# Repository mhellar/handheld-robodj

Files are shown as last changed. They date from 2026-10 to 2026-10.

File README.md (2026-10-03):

# Handheld Robo DJ

A pocket robot-voice DJ on an ESP32-S3. **SAM** (the 1982 Software Automatic Mouth speech synth) pre-renders a bank of
words into memory, and a "turntable deck" plays, scratches, stutters and reverses them over a drum machine, with a
16-step sequencer, granular and vocoder voice effects and a sci-fi HUD on a 128x128 OLED. Four buttons, one speaker.

The board is a single-sided PCB designed to be **milled on a desktop CNC** (all copper on the bottom, big pads, no
jumper wires). The modules plug into female headers, so there's no SMD soldering.

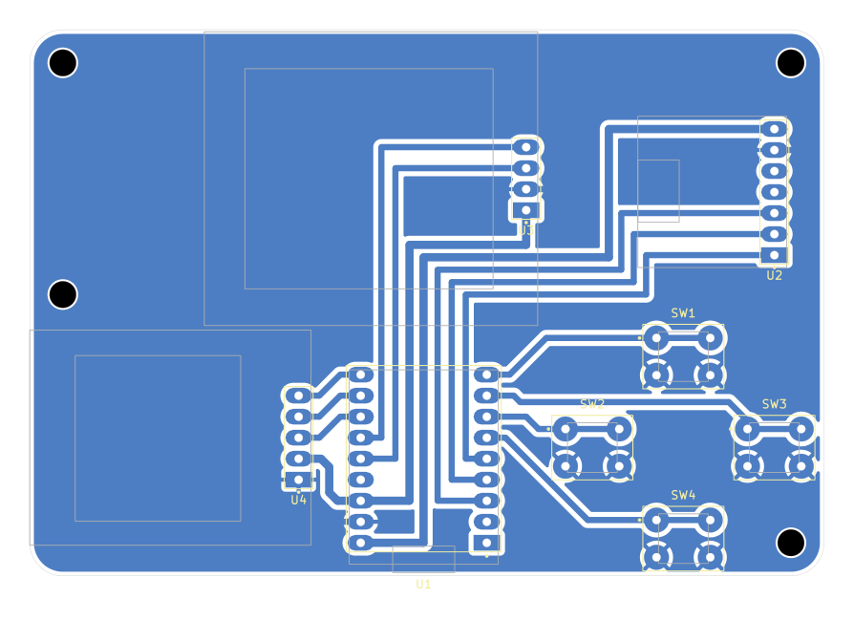
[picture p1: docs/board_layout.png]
board layout


## What's in here

| Folder | Contents |
|---|---|
| `firmware/handheld_robodj/` | The Robo DJ sketch (Arduino), SAM's C core bundled alongside |
| `firmware/handheld_bringup/` | Bring-up / test sketch: I2C scan, buttons, joystick, OLED, beep. Flash this first |
| `hardware/kicad/` | KiCad project (schematic, PCB, custom symbols + footprints in `s3_cnc.pretty`) |
| `hardware/cnc/` | Gerbers + Excellon drills, ready-made G-code for a Genmitsu Cubiko (GRBL), the FlatCAM script, a 1:1 print for checking parts fit, and `CNC_CHEATSHEET.txt` |
| `docs/` | Board layout image |

## Parts

| Ref | Part | Notes |
|---|---|---|
| U1 | ESP32-S3 **SuperMini** | 2x 1x9 female headers. One with PSRAM (e.g. 4 MB flash / 2 MB PSRAM) holds the most words |
| U2 | MAX98357A I2S amp breakout | 1x7 female header, VIN on 5 V, plus a small 4-8 ohm speaker |
| U3 | 1.5" 128x128 OLED, **SH1107**, I2C | 1x4 female header (VCC GND SCL SDA), e.g. GME128128-01-IIC |
| U4 | KY-023 joystick module | 1x5 female header. Swap its right-angle pins for straight ones. Not used by Robo DJ, the bring-up sketch tests it |
| SW1-SW4 | 6 mm tact buttons | the diamond: UP / LEFT / RIGHT / DOWN |
| | 100 x 70 mm single-sided copper clad | board is 96 x 66 mm, M3 holes |

## Pinout

| Function | GPIO |
|---|---|
| OLED SDA / SCL | 11 / 12 |
| Amp DIN / BCLK / LRC | 1 / 2 / 3 |
| Buttons UP / RIGHT / LEFT / DOWN | 7 / 6 / 5 / 4 (to GND, internal pull-ups) |
| Joystick X / Y / SW | 10 / 9 / 8 (on 3V3) |

## Build the firmware

1. Arduino IDE (or arduino-cli) with the **ESP32 core 3.x** and the **U8g2** library.
2. Board settings: **ESP32S3 Dev Module**, **USB CDC On Boot: Enabled**, **PSRAM: QSPI PSRAM** (it runs without PSRAM, with fewer words).
   arduino-cli FQBN: `esp32:esp32:esp32s3:CDCOnBoot=cdc,PSRAM=enabled`
3. Open `firmware/handheld_robodj/handheld_robodj.ino` and upload. Flash `handheld_bringup` first if you're bringing up a fresh board.

```
arduino-cli compile --fqbn esp32:esp32:esp32s3:CDCOnBoot=cdc,PSRAM=enabled firmware/handheld_robodj
arduino-cli upload  --fqbn esp32:esp32:esp32s3:CDCOnBoot=cdc,PSRAM=enabled -p COMx firmware/handheld_robodj
```

Tips:
- The OLED uses the `U8G2_SH1107_PIMORONI_128X128` constructor. The generic SH1107 one shifts the picture by 32 px.
- If the SuperMini sits silent after an upload, press its RST button. The auto-reset can leave it in the bootloader.
- Intermittent buttons on a milled board usually turn out to be a solder bridge between neighbouring 2.54 mm pads.
- `handheld_bringup` prints to Serial every 250 ms: run it with a serial monitor open.

## Controls

Diamond: **UP = SHIFT**, **LEFT = VOICE**, **RIGHT = BEAT**, **DOWN = FX**. Live hits play instantly. With REC on they're quantized into the 16 steps.

| Button | tap | double | triple | hold |
|---|---|---|---|---|
| VOICE | say the word | next word | random word | SCRATCH it (tempo-synced) |
| BEAT | kick | snare | clap | hi-hat roll |
| FX | next FX | GROOVE on/off | | STUTTER |
| SHIFT + VOICE | REC on/off | clear voice track | clear all | REVERSE |
| SHIFT + BEAT | next scratch style | tempo | chord progression | TAPE STOP |
| SHIFT + FX | volume | next robot voice (re-renders the words) | | |
| SHIFT alone | MUTATE (new words, same rhythm) | AUTO (random beat + words) | | UNDERWATER |

- **Voice FX:** CLEAN, CRUSH, ECHO, GRAIN (slow cloud of grains at mixed pitches), SWARM (dense detuned robot choir), VOX (16-band vocoder on a chord, words stay clear), CHOIR (pure vocoder).
- **Scratch styles:** BABY, CHIRP, TRANSFORM, TEAR, FLARE.
- **Robot voices:** ROBOT, SAM, ELF, E.T., STUFFY, OLD LADY.
- **Words:** HELLO, ROBOT, YEAH, ERROR, DANCE, BEEP, BOOP, SYSTEM, ONLINE, WOW, FRESH, SCRATCH, ONE-FOUR, OH NO, COMPUTER, PARTY, FUNKY, AWESOME, DOES NOT COMPUTE. Edit `bank[]` in the sketch to make it say anything.

## Make the board

The PCB is single-sided with all copper on **B.Cu**, made for isolation milling. The Gerbers in `hardware/cnc/` also work at
a board house as a 1-layer board.

Milling order (details in `hardware/cnc/CNC_CHEATSHEET.txt`): 0.1 mm 20° V-bit isolation, 1.0 mm drill, 2.0 mm drill,
then V-bit outline score. The `.nc` files are ready to run on a GRBL machine. The drill files are already patched by
`fix_drill_spinup.py`, which fixes the spindle start for GRBL laser mode. To regenerate with FlatCAM, set the
path at the top of `load_and_mirror.tcl` and run it (File > Scripting > Run Script). It mirrors the board, because the
copper is on the bottom.

Before milling, print `PRINT_1to1_fit_test.pdf` at 100% and check your modules against it. The OLED and joystick
outlines were measured from photos.

## Credits and license

- **SAM** (Software Automatic Mouth) by Mark Barton / Don't Ask Software (1982). C port by Sebastian Macke,
  ESP8266SAM by Earle F. Philhower III. The C core is bundled in `firmware/handheld_robodj/`.
- **U8g2** by olikraus; **esp-dsp** and the ESP32 Arduino core by Espressif.
- Co-created by **Mark Hellar** and **Claude** (Anthropic). PCB milled and soldered by Mark Hellar.

Licensed under the **GNU GPL v3** (see `LICENSE`), the same as the bundled SAM core.

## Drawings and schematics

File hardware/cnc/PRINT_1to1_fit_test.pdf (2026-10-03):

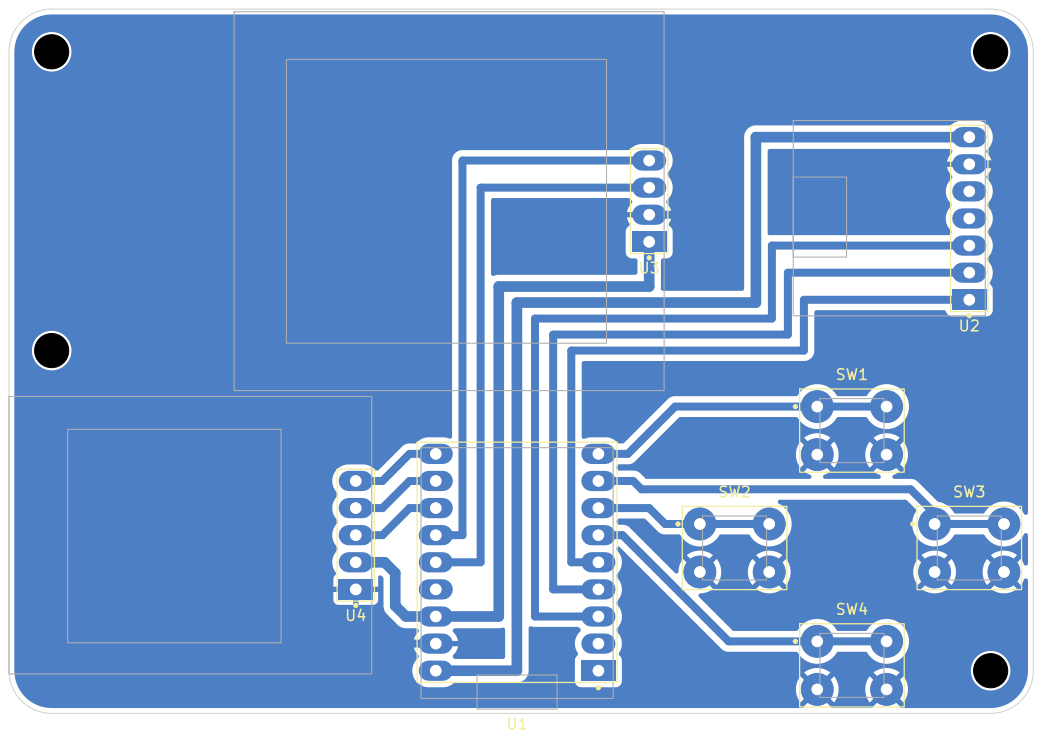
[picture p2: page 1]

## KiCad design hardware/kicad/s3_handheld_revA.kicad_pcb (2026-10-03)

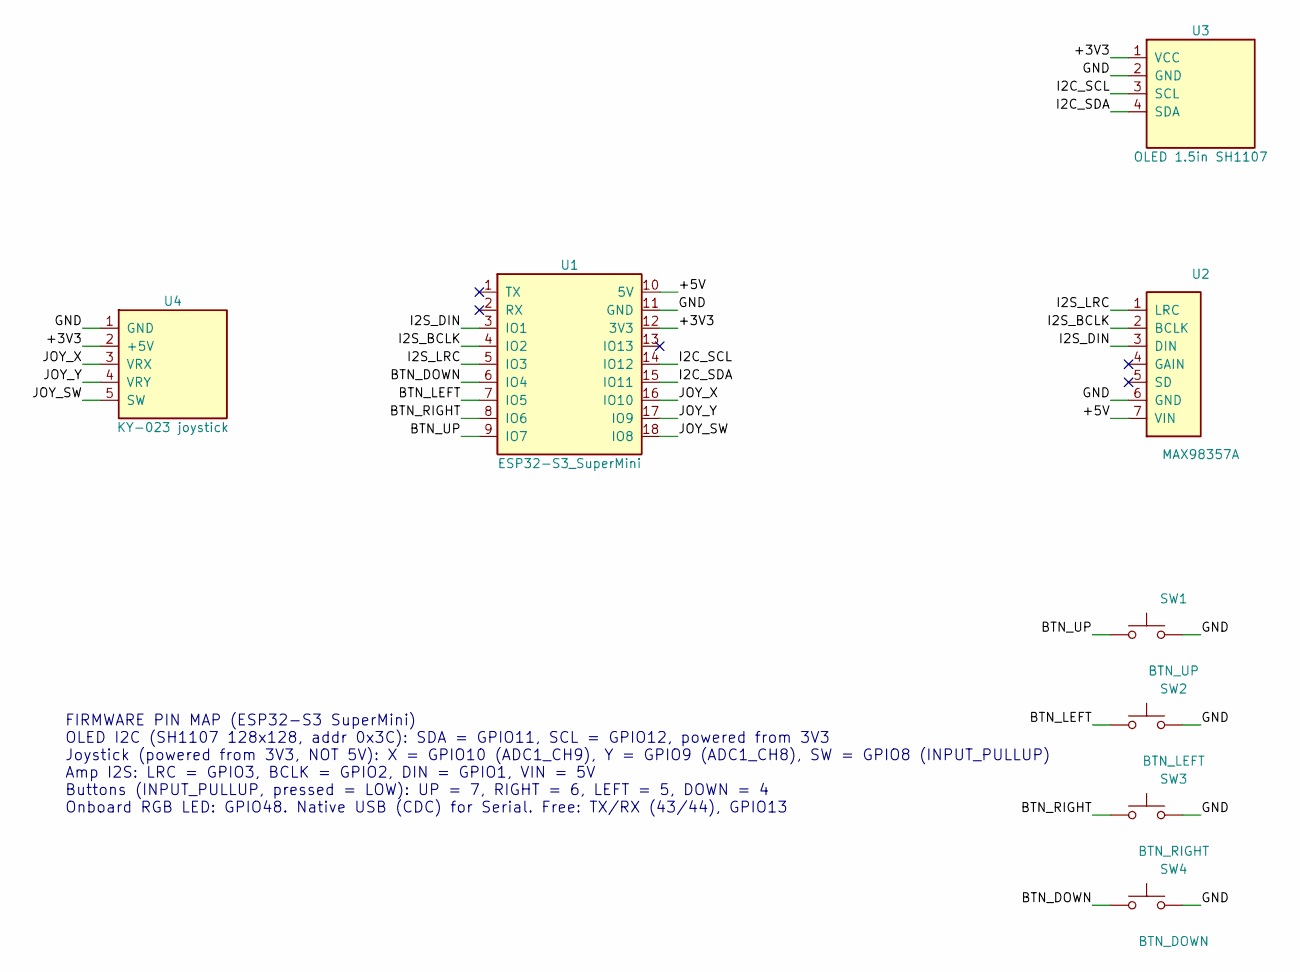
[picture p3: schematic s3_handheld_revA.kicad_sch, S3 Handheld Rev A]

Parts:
SW1: BTN_UP; SW_Tact_6mm_CNC
SW2: BTN_LEFT; SW_Tact_6mm_CNC
SW3: BTN_RIGHT; SW_Tact_6mm_CNC
SW4: BTN_DOWN; SW_Tact_6mm_CNC
U1: ESP32-S3_SuperMini; ESP32-S3_SuperMini_CNC
U2: MAX98357A; MAX98357A_Module_CNC
U3: OLED 1.5in SH1107; OLED_1.5in_128x128_I2C_CNC
U4: KY-023 joystick; Joystick_KY023_CNC

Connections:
/+3V3: U1.12 (3V3), U3.1 (VCC), U4.2 (+5V)
/+5V: U1.10 (5V), U2.7 (VIN)
/BTN_DOWN: SW4.1, U1.6 (IO4)
/BTN_LEFT: SW2.1, U1.7 (IO5)
/BTN_RIGHT: SW3.1, U1.8 (IO6)
/BTN_UP: SW1.1, U1.9 (IO7)
/GND: SW1.2, SW2.2, SW3.2, SW4.2, U1.11 (GND), U2.6 (GND), U3.2 (GND), U4.1 (GND)
/I2C_SCL: U1.14 (IO12), U3.3 (SCL)
/I2C_SDA: U1.15 (IO11), U3.4 (SDA)
/I2S_BCLK: U1.4 (IO2), U2.2 (BCLK)
/I2S_DIN: U1.3 (IO1), U2.3 (DIN)
/I2S_LRC: U1.5 (IO3), U2.1 (LRC)
/JOY_SW: U1.18 (IO8), U4.5 (SW)
/JOY_X: U1.16 (IO10), U4.3 (VRX)
/JOY_Y: U1.17 (IO9), U4.4 (VRY)

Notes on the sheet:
FIRMWARE PIN MAP (ESP32-S3 SuperMini) OLED I2C (SH1107 128x128, addr 0x3C): SDA = GPIO11, SCL = GPIO12, powered from 3V3 Joystick (powered from 3V3, NOT 5V): X = GPIO10 (ADC1_CH9), Y = GPIO9 (ADC1_CH8), SW = GPIO8 (INPUT_PULLUP) Amp I2S: LRC = GPIO3, BCLK = GPIO2, DIN = GPIO1, VIN = 5V Buttons (INP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

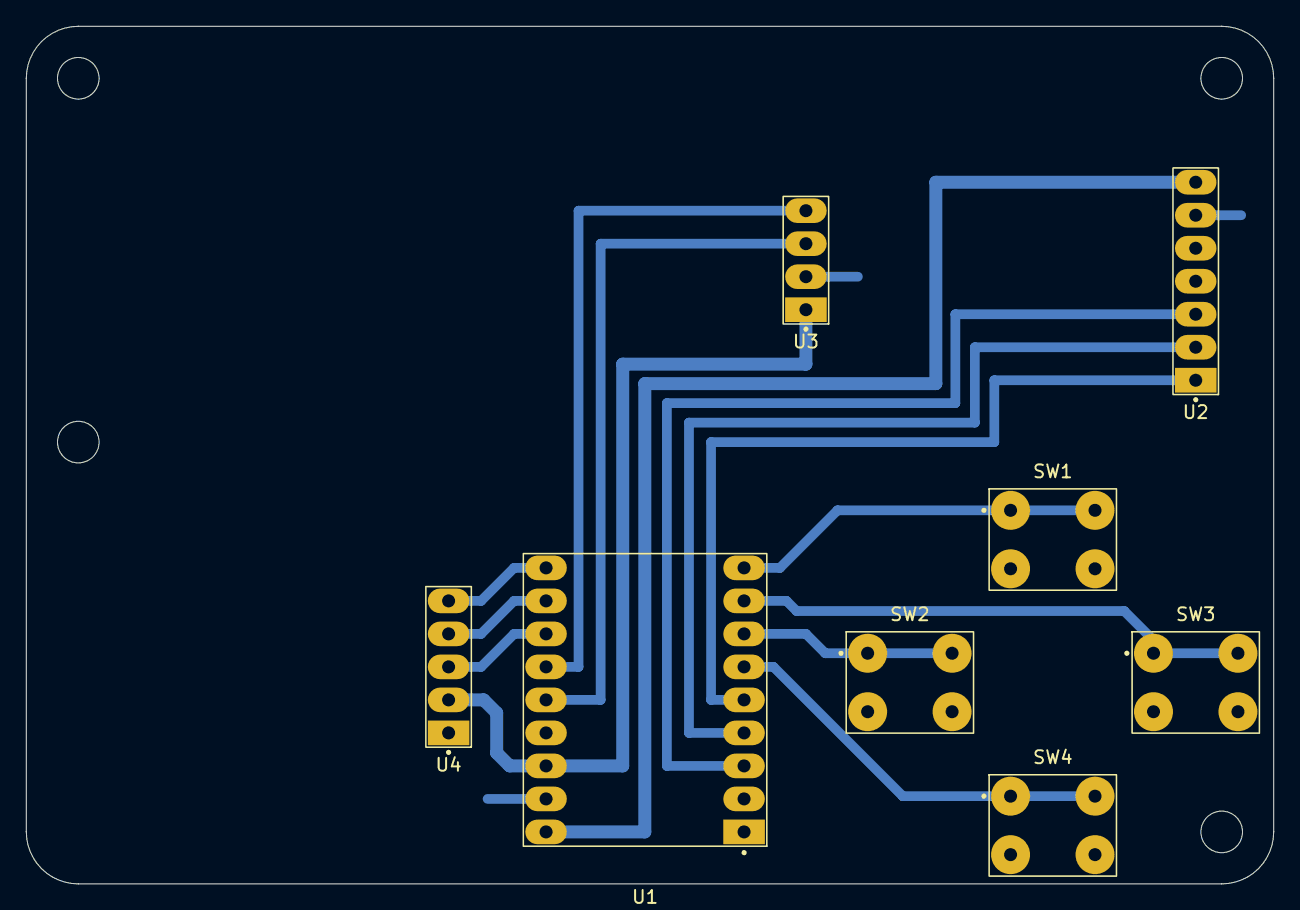
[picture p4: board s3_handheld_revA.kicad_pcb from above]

Board: 2 copper layers, 96.0 x 66.0 mm, 12 parts (0 on the bottom side), 15 nets.

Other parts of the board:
H1, H2, H3, H4: MountingHole_3.2mm_M3

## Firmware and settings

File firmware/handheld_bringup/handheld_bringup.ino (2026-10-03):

// S3 Handheld Rev A - bench bring-up test (ESP32-S3 SuperMini)
// Board: "ESP32S3 Dev Module", Tools > USB CDC On Boot: "Enabled", Serial Monitor 115200.
// Library: U8g2 (already installed). ESP32 Arduino core 3.x (prints a "legacy i2s driver" warning - harmless).
//
// On boot: I2C scan (OLED should answer at 0x3C). Then every 250 ms Serial prints joystick + buttons.
// OLED: joystick crosshair, raw X/Y, the 4 buttons + stick click, tone state.
// Onboard RGB LED: green while the stick is clicked, otherwise follows joystick X (blue..red).
// Buttons:
//   UP    = tone on/off (starts OFF)
//   RIGHT = next tone frequency (220/440/880/1760 Hz)
//   DOWN  = next volume (1..4, starts at 1 = quiet)
//   LEFT  = "joystick = pitch" mode on/off (X = pitch 110..1760 Hz, tone plays while on)
// Screen rotation: press LEFT + RIGHT together to step through 0/90/180/270 deg (saved in flash).
// On boot: a 0.4 s 880 Hz beep through the amp (speaker check).

#include <Arduino.h>
#include <Wire.h>
#include <U8g2lib.h>
#include <Preferences.h>
#include <esp_system.h>
#include <ESP_I2S.h>
#include <math.h>

// Pins - straight from the KiCad netlist (s3_handheld_revA)
const int PIN_SDA = 11, PIN_SCL = 12;
const int PIN_JOY_X = 10, PIN_JOY_Y = 9, PIN_JOY_SW = 8;   // joystick powered from 3V3
const int PIN_AMP_LRC = 3, PIN_AMP_BCLK = 2, PIN_AMP_DIN = 1;
const int PIN_RGB = 48;
const bool JOY_SW_ENABLED = true;   // re-enabled 10-02 after the GPIO8 solder blob was cleaned
const int BTN_PINS[4] = {7, 6, 4, 5};  // UP, RIGHT, DOWN, LEFT
const char *BTN_NAMES[4] = {"UP", "RIGHT", "DOWN", "LEFT"};

// GME128128-01-IIC needs the PIMORONI variant (x offset 0); the generic one wraps the picture by 32 px
U8G2_SH1107_PIMORONI_128X128_F_HW_I2C oled(U8G2_R0, /*reset=*/U8X8_PIN_NONE, /*clock=*/PIN_SCL, /*data=*/PIN_SDA);
bool oledOk = false;
Preferences prefs;
const u8g2_cb_t *ROTS[4] = {U8G2_R0, U8G2_R1, U8G2_R2, U8G2_R3};
uint8_t rot = 3;  // R3 = right way up on the milled board (Mark, 2026-10-01); LEFT+RIGHT cycles

void applyRotation() {
  oled.setDisplayRotation(ROTS[rot]);
  prefs.putUChar("orient", rot);
  Serial.printf("OLED rotation %d (%d deg)\n", rot, rot * 90);
}

I2SClass amp;
const int RATE = 44100;
const int BLOCK = 256;

volatile bool toneOn = false, joyPitch = false;
volatile int freqIdx = 1, volIdx = 0;
volatile float joyFreq = 440;
const float FREQS[4] = {220, 440, 880, 1760};
const float VOLS[4] = {0.03f, 0.08f, 0.20f, 0.45f};
volatile uint32_t ampWriteErrs = 0;
volatile uint32_t audioBlocks = 0;   // goes up ~172/s while the audio task is alive
const char *resetWhy = "?";

const char *resetReason() {
  switch (esp_reset_reason()) {
    case ESP_RST_POWERON: return "POWERON";
    case ESP_RST_SW: return "SW";
    case ESP_RST_PANIC: return "PANIC";
    case ESP_RST_INT_WDT: return "INT_WDT";
    case ESP_RST_TASK_WDT: return "TASK_WDT";
    case ESP_RST_WDT: return "WDT";
    case ESP_RST_BROWNOUT: return "BROWNOUT";
    case ESP_RST_DEEPSLEEP: return "DEEPSLEEP";
    case ESP_RST_EXT: return "EXT";
    case ESP_RST_USB: return "USB";
    default: return "OTHER";
  }
}

bool setupAmp() {
  amp.setPins(PIN_AMP_BCLK, PIN_AMP_LRC, PIN_AMP_DIN);  // bclk, ws (LRC), dout
  bool ok = amp.begin(I2S_MODE_STD, RATE, I2S_DATA_BIT_WIDTH_16BIT, I2S_SLOT_MODE_STEREO);
  Serial.printf("AMP I2S (ESP_I2S) begin=%s  BCLK %d LRC %d DIN %d\n", ok ? "OK" : "FAILED", PIN_AMP_BCLK, PIN_AMP_LRC, PIN_AMP_DIN);
  return ok;
}

void audioTask(void *) {
  static int16_t outBuf[BLOCK * 2];
  float phase = 0;
  for (;;) {
    float vol = VOLS[volIdx];
    float f = joyPitch ? joyFreq : FREQS[freqIdx];
    float step = 2.0f * PI * f / RATE;
    bool on = toneOn || joyPitch;
    for (int i = 0; i < BLOCK; i++) {
      float v = 0;
      if (on) { v = sinf(phase) * vol; phase += step; if (phase > 2 * PI) phase -= 2 * PI; }
      int16_t s = (int16_t)(v * 32767);
      outBuf[i * 2] = s; outBuf[i * 2 + 1] = s;
    }
    if (amp.write((uint8_t *)outBuf, sizeof(outBuf)) != sizeof(outBuf)) ampWriteErrs++;
    audioBlocks++;
  }
}

void setLed(uint8_t r, uint8_t g, uint8_t b) {
#if ESP_ARDUINO_VERSION_MAJOR >= 3
  rgbLedWrite(PIN_RGB, r, g, b);
#else
  neopixelWrite(PIN_RGB, r, g, b);
#endif
}

void i2cScan() {
  Wire.begin(PIN_SDA, PIN_SCL);
  int found = 0;
  Serial.print("I2C scan (SDA 11, SCL 12):");
  for (uint8_t a = 1; a < 127; a++) {
    Wire.beginTransmission(a);
    if (Wire.endTransmission() == 0) { Serial.printf(" 0x%02X", a); found++; if (a == 0x3C || a == 0x3D) oledOk = true; }
  }
  Serial.println(found ? "" : " nothing found - check OLED VCC/GND/SDA/SCL and the header orientation");
}

void drawOled(int jx, int jy, bool pressed[4], bool click) {
  oled.clearBuffer();
  oled.setFont(u8g2_font_6x10_tf);
  oled.drawStr(0, 9, "S3 Handheld revA");
  char r[8]; snprintf(r, sizeof r, "R%d", rot); oled.drawStr(110, 9, r);
  // joystick box 64x64 at the left, crosshair at the stick position
  const int bx = 0, by = 14, bw = 64;
  oled.drawFrame(bx, by, bw, bw);
  int cx = bx + 1 + jx * (bw - 3) / 4095, cy = by + 1 + jy * (bw - 3) / 4095;
  if (click) oled.drawDisc(cx, cy, 4); else oled.drawCircle(cx, cy, 4);
  char line[24];
  snprintf(line, sizeof line, "X %4d", jx); oled.drawStr(70, 24, line);
  snprintf(line, sizeof line, "Y %4d", jy); oled.drawStr(70, 36, line);
  oled.drawStr(70, 48, click ? "CLICK" : "");
  // button diamond at the bottom right
  const int dx = 96, dy = 100, s = 12;
  const int bxy[4][2] = {{0, -s}, {s, 0}, {0, s}, {-s, 0}};  // UP RIGHT DOWN LEFT
  for (int i = 0; i < 4; i++) {
    if (pressed[i]) oled.drawBox(dx + bxy[i][0] - 4, dy + bxy[i][1] - 4, 9, 9);
    else oled.drawFrame(dx + bxy[i][0] - 4, dy + bxy[i][1] - 4, 9, 9);
  }
  snprintf(line, sizeof line, "%s %s", (toneOn || joyPitch) ? "TONE" : "tone",
           joyPitch ? "joy" : String((int)FREQS[freqIdx]).c_str());
  oled.drawStr(0, 92, line);
  snprintf(line, sizeof line, "vol %d", volIdx + 1); oled.drawStr(0, 104, line);
  if (ampWriteErrs) oled.drawStr(0, 116, "AMP ERR");
  snprintf(line, sizeof line, "up %lus %s", millis() / 1000, resetWhy);
  oled.drawStr(0, 127, line);
  oled.sendBuffer();
}

void setup() {
  Serial.begin(115200);
  delay(1500);  // give native USB time to enumerate
  resetWhy = resetReason();
  Serial.printf("\n=== S3 Handheld Rev A bring-up === last reset: %s\n", resetWhy);
  for (int i = 0; i < 4; i++) pinMode(BTN_PINS[i], INPUT_PULLUP);
  if (JOY_SW_ENABLED) pinMode(PIN_JOY_SW, INPUT_PULLUP);
  analogReadResolution(12);
  analogSetPinAttenuation(PIN_JOY_X, ADC_11db);
  analogSetPinAttenuation(PIN_JOY_Y, ADC_11db);

  i2cScan();
  if (oledOk) {
    oled.setBusClock(400000);
    oled.begin();
    oled.setContrast(200);
    prefs.begin("handheld", false);
    rot = prefs.getUChar("orient", 3) & 3;
    applyRotation();
    Serial.println("OLED found - drawing");
  } else {
    Serial.println("!! no OLED at 0x3C/0x3D - continuing without it");
  }

  if (!setupAmp()) Serial.println("!! I2S setup failed - see codes above");
  xTaskCreatePinnedToCore(audioTask, "audio", 4096, NULL, 5, NULL, 0);
  // boot beep: 880 Hz, volume 3, 0.4 s
  freqIdx = 2; volIdx = 2; toneOn = true;
  delay(400);
  toneOn = false; freqIdx = 1; volIdx = 0;
  Serial.println("UP=tone  RIGHT=freq  DOWN=volume  LEFT=joystick-pitch mode\n");
}

void loop() {
  static uint32_t loopStart = 0, loopMax = 0;
  uint32_t nowMs = millis();
  if (loopStart) loopMax = max(loopMax, nowMs - loopStart);
  loopStart = nowMs;
  static bool prev[4] = {true, true, true, true};
  static uint32_t lastEdge[4] = {0};
  bool pressed[4];
  for (int i = 0; i < 4; i++) {
    bool now = digitalRead(BTN_PINS[i]);
    pressed[i] = !now;
    if (now != prev[i] && millis() - lastEdge[i] > 30) {
      lastEdge[i] = millis();
      prev[i] = now;
      if (!now) {
        if (i == 0) toneOn = !toneOn;
        if (i == 1) freqIdx = (freqIdx + 1) % 4;
        if (i == 2) volIdx = (volIdx + 1) % 4;
        if (i == 3) joyPitch = !joyPitch;
        Serial.printf(">> %s  tone=%s %.0fHz vol=%d joyPitch=%s\n", BTN_NAMES[i],
                      toneOn ? "ON" : "off", FREQS[freqIdx], volIdx + 1, joyPitch ? "ON" : "off");
      }
    }
  }
  // LEFT + RIGHT together: next screen rotation
  static bool comboPrev = false;
  bool combo = pressed[1] && pressed[3];
  if (combo && !comboPrev && oledOk) { rot = (rot + 1) & 3; applyRotation(); }
  comboPrev = combo;

  bool click = JOY_SW_ENABLED && !digitalRead(PIN_JOY_SW);
  int jx = analogRead(PIN_JOY_X), jy = analogRead(PIN_JOY_Y);
  joyFreq = 110.0f * powf(2.0f, jx / 4095.0f * 4.0f);  // 4 octaves, 110..1760 Hz

  static uint32_t lastLed = 0;
  if (millis() - lastLed >= 20) {
    lastLed = millis();
    uint8_t v = jx * 255 / 4095;
    if (click) setLed(0, 40, 0); else setLed(v / 4, 0, (255 - v) / 4);
  }

  static uint32_t lastDraw = 0;
  if (oledOk && millis() - lastDraw >= 50) {
    lastDraw = millis();
    drawOled(jx, jy, pressed, click);
  }

  static uint32_t lastPrint = 0;
  if (millis() - lastPrint >= 250) {
    lastPrint = millis();
    static int xmin = 4095, xmax = 0, ymin = 4095, ymax = 0;
    xmin = min(xmin, jx); xmax = max(xmax, jx); ymin = min(ymin, jy); ymax = max(ymax, jy);
    Serial.printf("JOY X %4d (%4d..%4d) Y %4d (%4d..%4d) SW=%d | BTN", jx, xmin, xmax, jy, ymin, ymax, click);
    for (int i = 0; i < 4; i++) Serial.printf(" %s=%d", BTN_NAMES[i], pressed[i]);
    if (ampWriteErrs) Serial.printf(" | AMP ERR %lu", (unsigned long)ampWriteErrs);
    Serial.printf(" | up %lus loopMax %lums audio %lu tone=%d", millis() / 1000, (unsigned long)loopMax,
                  (unsigned long)audioBlocks, (int)(toneOn || joyPitch));
    loopMax = 0;
    Serial.println();
  }
}

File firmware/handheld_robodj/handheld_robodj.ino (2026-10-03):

/*
  HANDHELD ROBO DJ - robot voice + turntable scratching + 16-step sequencer (s3_handheld_revA)
  =========================================================================================
  The robot voice is SAM (Software Automatic Mouth, 1982) - the C core from earlephilhower/ESP8266SAM
  (GPL v3) is bundled in this folder. At boot SAM pre-renders a bank of words into memory; a
  "turntable deck" then plays, scratches, stutters and reverses them over a drum machine.

  Diamond:   UP = SHIFT    LEFT = VOICE    RIGHT = BEAT    DOWN = FX
  Live hits play the instant you press. With REC on they're quantized into the 16 steps.

  VOICE (LEFT)    tap = say the word   tap-tap = next word   tap-tap-tap = random word
                  hold = SCRATCH it (tempo-synced, style below)
  BEAT  (RIGHT)   tap = kick   tap-tap = snare   tap-tap-tap = clap    hold = hi-hat roll
  FX    (DOWN)    tap = next FX (CLEAN CRUSH ECHO GRAIN SWARM VOX CHOIR)
                  GRAIN = slow-stretched cloud of grains at mixed pitches; SWARM = dense detuned robot choir
                  VOX = 16-band vocoder on a chord + some dry voice (words stay clear)
                  CHOIR = the pure vocoder (bold, words melt into the chord)
                  the vocoder chord follows a progression, one chord per bar
                  double = GROOVE on/off    hold = STUTTER (r-r-r-robot)
  SHIFT + VOICE   tap = REC on/off   double = clear voice track   triple = clear all   hold = REVERSE
  SHIFT + BEAT    tap = next scratch style (BABY CHIRP TRANSFORM TEAR FLARE)
                  double = tempo (100 110 120 80 90)   triple = chord progression   hold = TAPE STOP
  SHIFT + FX      tap = volume (4 steps)   double = next robot voice (re-renders the words)
  SHIFT alone     tap = MUTATE (new words, same rhythm)   double = AUTO (random beat + words)
                  hold = UNDERWATER

  Board: "ESP32S3 Dev Module", USB CDC On Boot: Enabled, PSRAM: "QSPI PSRAM" (works without, fewer words).
  Libraries: U8g2. ESP32 core 3.x (ESP_I2S).
*/

#include <Arduino.h>
#include <Wire.h>
#include <U8g2lib.h>
#include <Preferences.h>
#include <ESP_I2S.h>
#include "esp_dsp.h"
#include "SamData.h"
#include "sam.h"
#include "reciter.h"

// ---------------- pins ----------------
#define PIN_SDA   11
#define PIN_SCL   12
#define AMP_BCLK  2
#define AMP_LRC   3
#define AMP_DIN   1
#define PIN_RGB   48
#define PIN_SHIFT 7     // UP
#define PIN_BEAT  6     // RIGHT
#define PIN_FX    4     // DOWN
#define PIN_VOICE 5     // LEFT

#define FS     22050          // SAM's native rate
#define INV_FS (1.0f / FS)
#define BLOCK  128

const float VOLS[4] = {0.06f, 0.12f, 0.22f, 0.35f};
volatile int volIdx = 1;

// ---------------- types first (Arduino auto-prototypes) ----------------
struct Btn {
  uint8_t pin;
  bool off, down, cmd, longOn, other;
  uint32_t tDown, tUp, tChange, cmdDeadline;
  int taps, cmdTaps;
};
struct Word { const char* text; uint32_t off, len; };
struct Step { int8_t word; uint8_t drum; uint8_t flags; bool skip; };
struct Voice { const char* name; uint8_t speed, pitch, throat, mouth; };

enum { DR_KICK = 1, DR_SNARE = 2, DR_CLAP = 4, DR_HAT = 8 };
enum { SF_SCRATCH = 1, SF_REV = 2 };
enum { FX_CLEAN, FX_CRUSH, FX_ECHO, FX_GRAIN, FX_SWARM, FX_VOX, FX_CHOIR, FX_COUNT };
const char* FX_NAMES[] = {"CLEAN", "CRUSH", "ECHO", "GRAIN", "SWARM", "VOX", "CHOIR"};
enum { SC_BABY, SC_CHIRP, SC_TRANS, SC_TEAR, SC_FLARE, SC_COUNT };
const char* SC_NAMES[] = {"BABY", "CHIRP", "TRANSFORM", "TEAR", "FLARE"};
const int TEMPOS[] = {100, 110, 120, 80, 90};
const Voice VOICES[] = {
  {"ROBOT", 92, 60, 190, 190}, {"SAM", 72, 64, 128, 128}, {"ELF", 72, 64, 110, 160},
  {"E.T.", 100, 64, 150, 200}, {"STUFFY", 82, 72, 110, 105}, {"OLD LADY", 82, 32, 145, 145},
};
const int NVOICES = 6;

Word bank[] = {
  {"HELLO"}, {"ROBOT"}, {"YEAH"}, {"ERROR"}, {"DANCE"}, {"BEEP"}, {"BOOP"}, {"SYSTEM"},
  {"ONLINE"}, {"WOW"}, {"FRESH"}, {"SCRATCH"}, {"ONE"}, {"TWO"}, {"THREE"}, {"FOUR"},
  {"OH NO"}, {"COMPUTER"}, {"PARTY"}, {"FUNKY"}, {"AWESOME"}, {"DOES NOT COMPUTE"},
};
const int NWORDS = sizeof(bank) / sizeof(bank[0]);

U8G2_SH1107_PIMORONI_128X128_F_HW_I2C oled(U8G2_R0, U8X8_PIN_NONE, PIN_SCL, PIN_SDA);
Preferences prefs;
I2SClass amp;

void drawFrame();

// =====================================================================
// SAM -> sample pool
// =====================================================================
SamData* samdata;
int8_t* pool = nullptr;
uint32_t poolSize = 0, poolPos = 0;
volatile bool bankBusy = true;
volatile int voiceIdx = 0;
int renderProgress = 0;

static void samByte(void*, unsigned char b) { if (poolPos < poolSize) pool[poolPos++] = (int8_t)((int)b - 128); }

bool sayToPool(const char* text, const Voice& v) {
  char input[256];
  int n = 0;
  for (; text[n] && n < 200; n++) input[n] = toupper((int)text[n]);
  input[n] = 0;
  strcat(input, "[");
  samdata = new SamData;
  if (!samdata) return false;
  EnableSingmode(0);
  SetSpeed(v.speed); SetPitch(v.pitch); SetThroat(v.throat); SetMouth(v.mouth);
  bool ok = TextToPhonemes(input);
  if (ok) { SetInput(input); SAMMain(samByte, nullptr); }
  delete samdata;
  return ok;
}

void renderBank(int vi) {
  bankBusy = true;
  delay(30);                                   // let the audio task notice
  poolPos = 0;
  for (int i = 0; i < NWORDS; i++) {
    renderProgress = i;
    drawFrame();
    uint32_t start = poolPos;
    bank[i].off = start; bank[i].len = 0;
    if (poolSize - poolPos < FS / 2) continue; // pool full: skip the rest
    if (!sayToPool(bank[i].text, VOICES[vi])) { poolPos = start; continue; }
    uint32_t a = start, b = poolPos;            // trim silence at both ends
    while (a < b && abs(pool[a]) < 4) a++;
    while (b > a && abs(pool[b - 1]) < 4) b--;
    bank[i].off = a; bank[i].len = b > a + 8 ? b - a : 0;
  }
  renderProgress = NWORDS;
  Serial.printf("voice %s: %u bytes for %d words\n", VOICES[vi].name, poolPos, NWORDS);
  bankBusy = false;
}

static inline float wordAt(int w, float p) {
  const Word& wd = bank[w];
  if (p < 0 || p >= wd.len - 1) return 0;
  int i = (int)p; float f = p - i;
  float a = pool[wd.off + i], b = pool[wd.off + i + 1];
  return (a + (b - a) * f) * (1.0f / 128.0f);
}

// =====================================================================
// DSP helpers + drums (from the improv engine)
// =====================================================================
float sineTab[1025];
static inline float wrap1(float p) { return p - floorf(p); }
static inline float fsin(float ph) {
  float x = ph * 1024.0f; int i = (int)x; float f = x - i; i &= 1023;
  return sineTab[i] + (sineTab[i + 1] - sineTab[i]) * f;
}
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
